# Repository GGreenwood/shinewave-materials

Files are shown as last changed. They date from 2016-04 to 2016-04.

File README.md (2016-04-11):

This repository contains supporting materials for the upcoming tasks to be completed before the Shinewave Kickstarter.

Shinewave is a project aimed at competitive Super Smash Bros players that seeks to modify and improve GameCube controllers with programmable LEDs and various USB functionalities. The electronics and firmware have already been prototyped and are showcased on my blog at [Electric Exploits](http://electricexploits.net/).

However, official clear controller backs(necessary to see the LEDs) are difficult to find, tend to be in used condition, and cost about $40 each. Therefore, I hope to produce my own replica of the official injection molded backs.

Since I will have full control over the new model, I hope to include several modifications that will make assembly easier and allow for easy USB connections.

# Contents

| Folder | Contents |
| --- | --- |
| `./controller-model` | Rough 3D scan of a GameCube controller back |
| `./shinewave-board/main` | Schematics and board for the main Shinewave PCB |
| `./shinewave-board/leds` | Schematics and board for each LED |

# Todo

## Produce injection molded clear backs

It is the most important to produce a piece that mates well with the official top half of the shell, so that the two pieces join together seamlessly. The controller has a lot of odd curves in its geometry, so this may be difficult.

I tried taking a 3D scan of the controller back with a NextEngine desktop scanner, but the scan quality wasn't too great. I uploaded it anyways, because it may be a good place to start.

Additionally, there are several modifications that I would like to make to the base model.

## PCB mounting points

As it stands, I have been either hot gluing parts into the case, or letting wire tension keep them in place. This works fine for small scales of production, but would error-prone in larger quantities.

I would like to include some mounting mechanism for the main PCB, and each of the five LED PCBs. I'm not sure what kind of mounting mechanism would be injection-molding friendly.

In the album below, I've marked the approximate mounting point locations. The LEDs are marked by X's, while the Shinewave PCB is marked by the rectangle on the back. Additionally, the USB port is the filled inner rectangle on the back.

[PCB Mounting points](http://imgur.com/a/13wrS)

## USB access

In order to use the controller as a USB joystick, update the firmware, or modify the LEDs without disassembling the controller, a microUSB port in the back would be necessary. The port would be orthogonal(probably) to the main Shinewave PCB, which will have a right-angle microUSB connector, similar to [this](http://www.mouser.com/ProductDetail/Hirose-Connector/ZX80-B-5S/?qs=XQjbzJWzFPUrLcP5tM9rJg%3D%3D).

## Misc

Finally, I would like to get an opinion on the following tasks

 * Choosing good board to board connectors, and finding a source for the custom length wires
 * Finding a medium-run manufacturer to do production and PCB assembly, and getting a quote

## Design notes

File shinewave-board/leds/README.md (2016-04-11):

#Schematic


#Board


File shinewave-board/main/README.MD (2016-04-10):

#Board


#Schematic


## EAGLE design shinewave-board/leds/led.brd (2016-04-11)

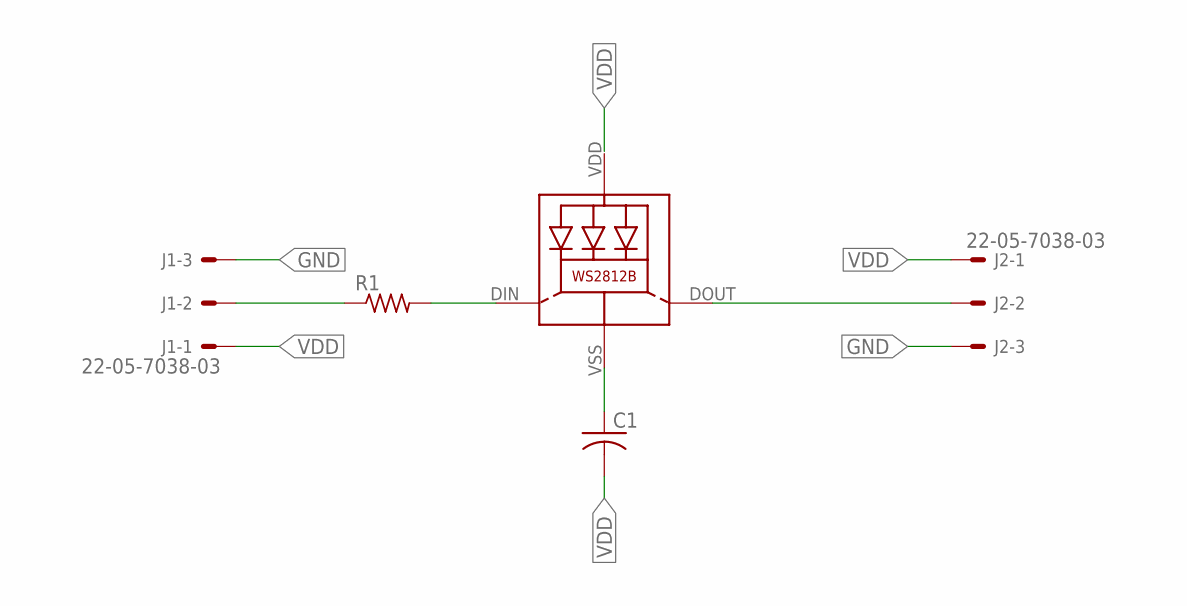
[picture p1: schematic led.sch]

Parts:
C1: C-USC0603; C0603
J1, J2: 22-05-7038-03; 7395-03
LED1: WS2812B
R1: R-US_R0603; R0603

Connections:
GND: C1.1, J1.3, J2.3, LED1.VSS (GND)
unnamed: J1.2, R1.1
unnamed: LED1.DIN (DI), R1.2
unnamed: J2.2, LED1.DOUT (DO)
VDD: C1.2, J1.1, J2.1, LED1.VDD

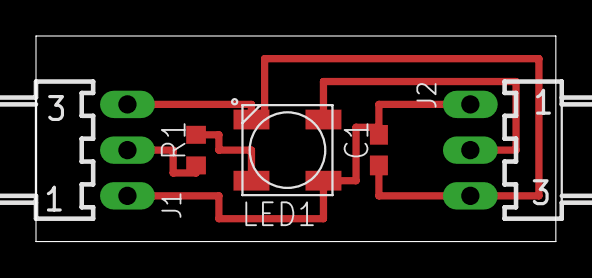
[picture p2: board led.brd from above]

Board: 2 copper layers, 28.9 x 11.4 mm, 5 parts (0 on the bottom side), 5 nets.

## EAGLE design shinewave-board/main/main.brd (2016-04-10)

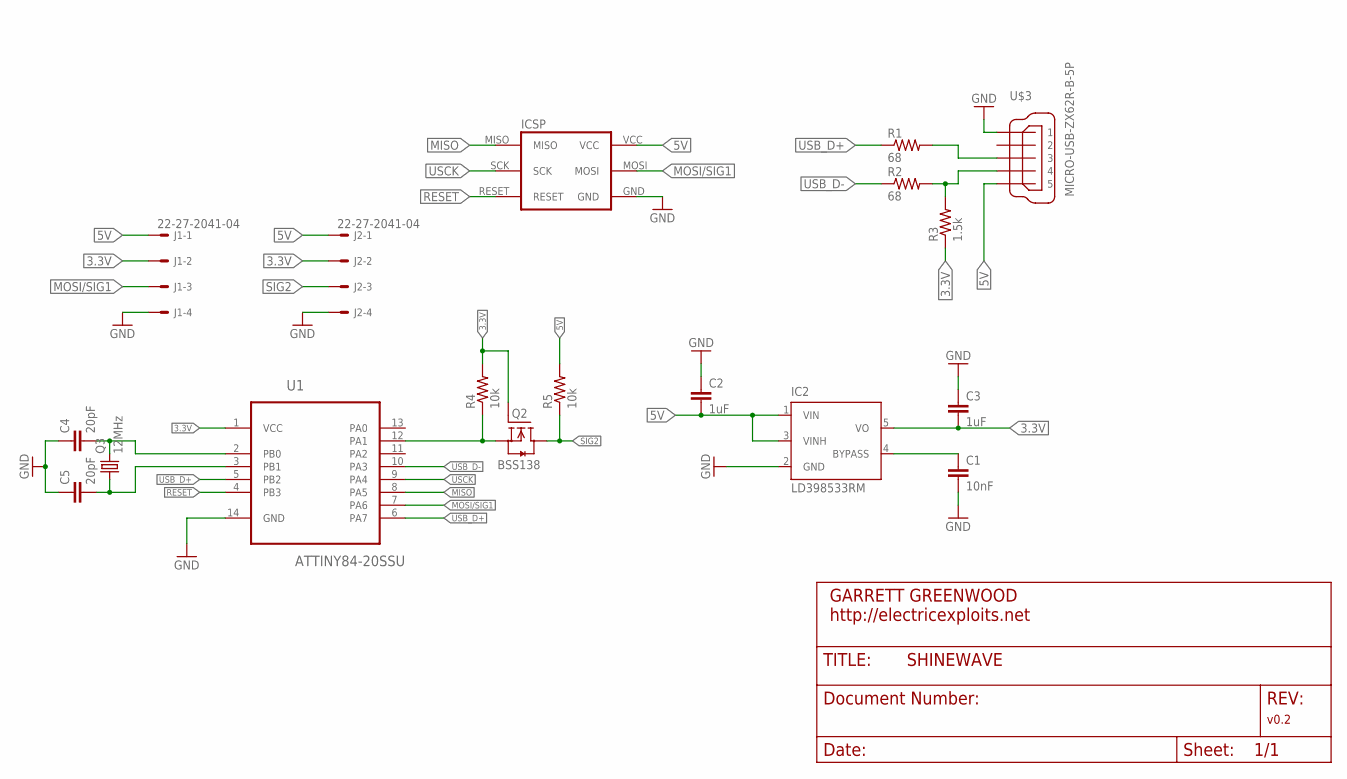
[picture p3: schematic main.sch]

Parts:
C1: 10nF; C0603
C2, C3: 1uF; C0603
C4, C5: 20pF; C0603
IC2: LD398533RM; SOT23-5L
J1, J2: 22-27-2041-04; 6410-04
Q2: BSS138; SOT23
Q3: 12MHz; CTS406
R1, R2: 68; R0603
R3: 1.5k; R0603
R4, R5: 10k; R0603
U1: ATTINY84-20SSU; SOIC127P600X175-14N
U$1: ICSP_POGO_INTERFACE; ICSP_SMD
U$3: MICRO-USB-ZX62R-B-5P; ZX62R-B-5P

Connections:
3.3V: C3.2, IC2.5 (VO), J1.2, J2.2, Q2.1 (G), R3.1, R4.2, U1.1 (VCC)
5V: C2.2, IC2.1 (VIN), IC2.3 (VINH), J1.1, J2.1, R5.2, U$1.VCC, U$3.5
GND: C1.2, C2.1, C3.1, C4.1, C5.1, IC2.2 (GND), J1.4, J2.4, U1.14 (GND), U$1.GND, U$3.1
MISO: U1.8 (PA5), U$1.MISO
MOSI/SIG1: J1.3, U1.7 (PA6), U$1.MOSI
unnamed: Q2.2 (S), R4.1, U1.12 (PA1)
unnamed: C1.1, IC2.4 (BYPASS)
unnamed: R1.2, U$3.3
unnamed: R2.2, R3.2, U$3.4
RESET: U1.4 (PB3), U$1.RESET
SIG2: J2.3, Q2.3 (D), R5.1
USB_D+: R1.1, U1.5 (PB2), U1.6 (PA7)
USB_D-: R2.1, U1.10 (PA3)
USCK: U1.9 (PA4), U$1.SCK
XTAL1: C4.2, Q3.3 (2), U1.2 (PB0)
XTAL2: C5.2, Q3.1, U1.3 (PB1)

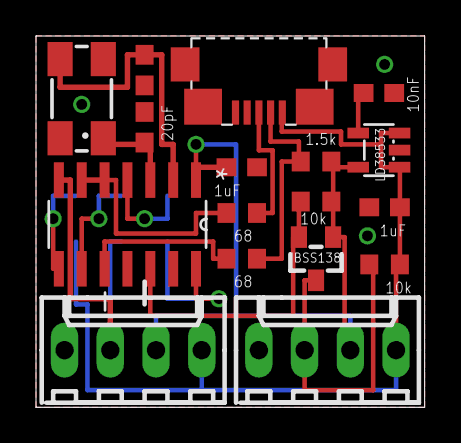
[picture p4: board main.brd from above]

Board: 2 copper layers, 21.6 x 20.6 mm, 18 parts (0 on the bottom side), 16 nets.

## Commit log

2016-04-10 Added main shinewave board and schematics
    [main.brd, main.sch]
2016-04-11 Added LED board and schematics
    [led.brd, led.sch]
2016-04-11 Added mounting point images

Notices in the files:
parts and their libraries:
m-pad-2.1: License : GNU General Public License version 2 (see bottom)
